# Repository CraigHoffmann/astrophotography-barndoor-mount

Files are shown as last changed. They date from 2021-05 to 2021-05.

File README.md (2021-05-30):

# Camera Barndoor Tracking Mount

Desktop barndoor mount for astrophotography with phd2/ascom autoguiding interface.

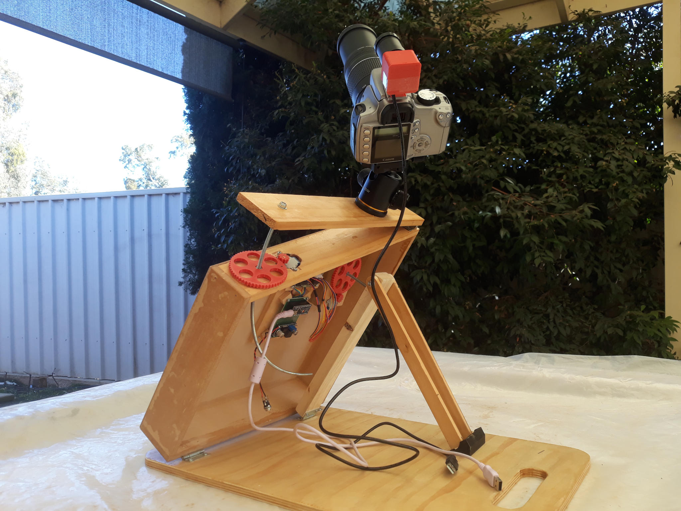
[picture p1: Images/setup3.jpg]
setup3


This started out as a basic barndoor mount with a hinge mounted on a tripod like many others.  However the cheap tripod I had wobbled too much and I decided to convert it into a tabletop mount.  I added an adjustable altitude axis for easy setup, then thought why not add an ascom interface so that it can be used with phd2 autoguiding for greater accuracy.  Now it a bit odd for a mount to be half alt/az and half equatorial axis (in this case Altitude and Right Ascention), but this seems to work fine for the phd2 guiding.  If polar aligned properly the altitude axis is almost redundant anyway.

The whole unit can be collapsed down for transport and storage.

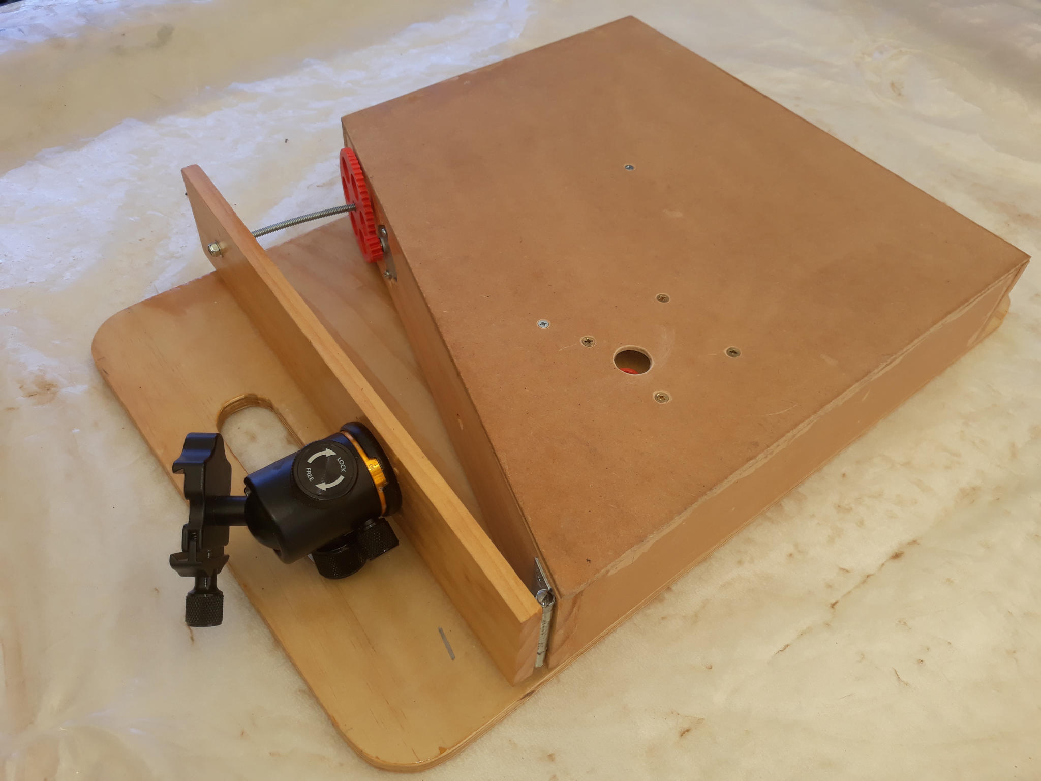
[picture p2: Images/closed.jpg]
closed


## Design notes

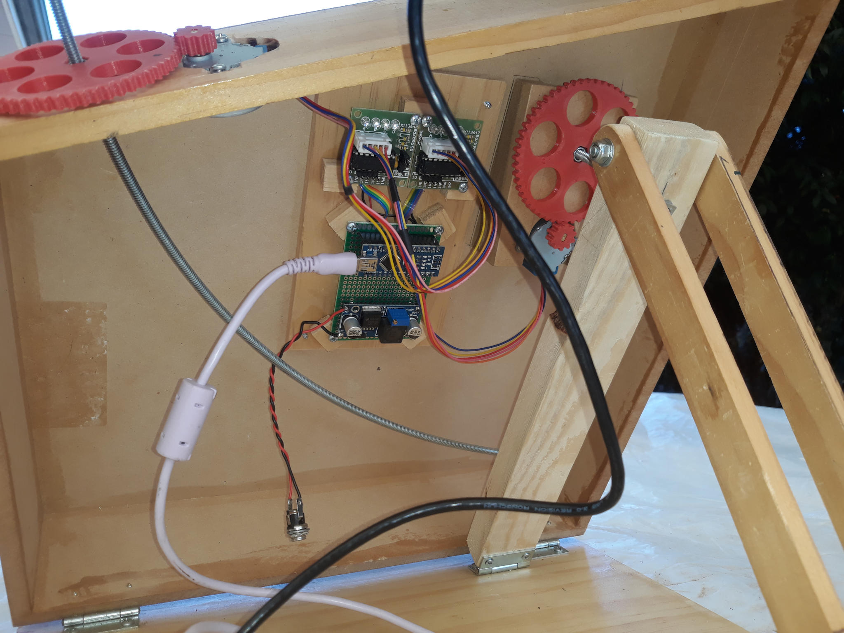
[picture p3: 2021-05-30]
Images/inside.jpg

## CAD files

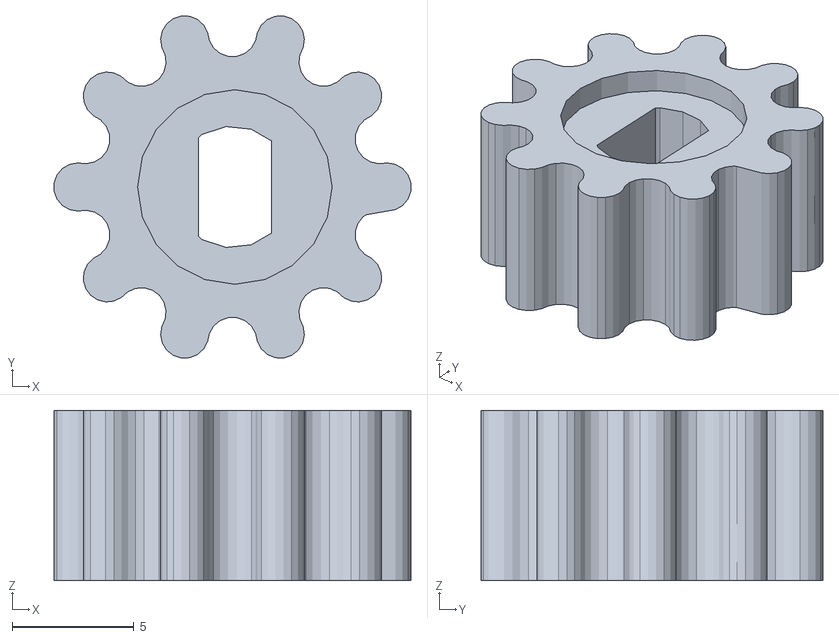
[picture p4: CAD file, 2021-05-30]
3Dprint/Barn Door Little gear.stl
14.7 x 14.1 x 7.00

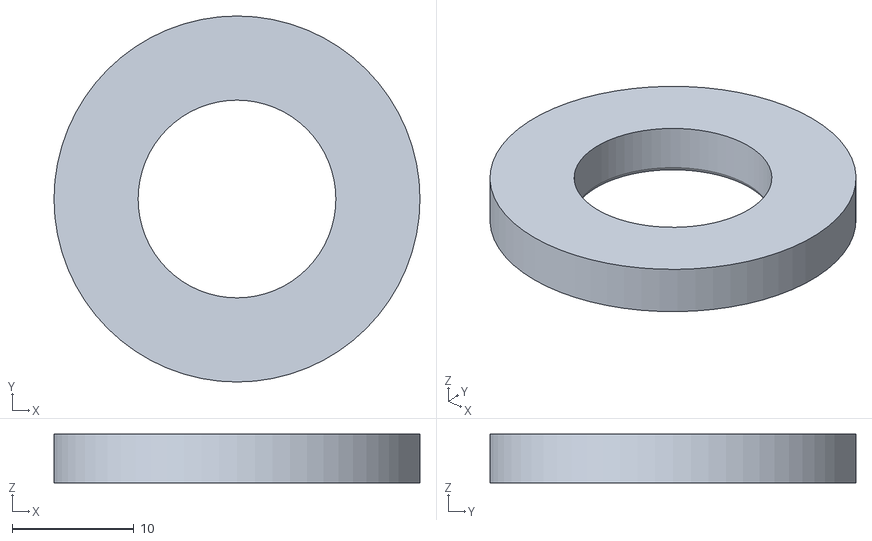
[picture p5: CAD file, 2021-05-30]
3Dprint/Barn Door ring.stl
30.0 x 30.0 x 4.00

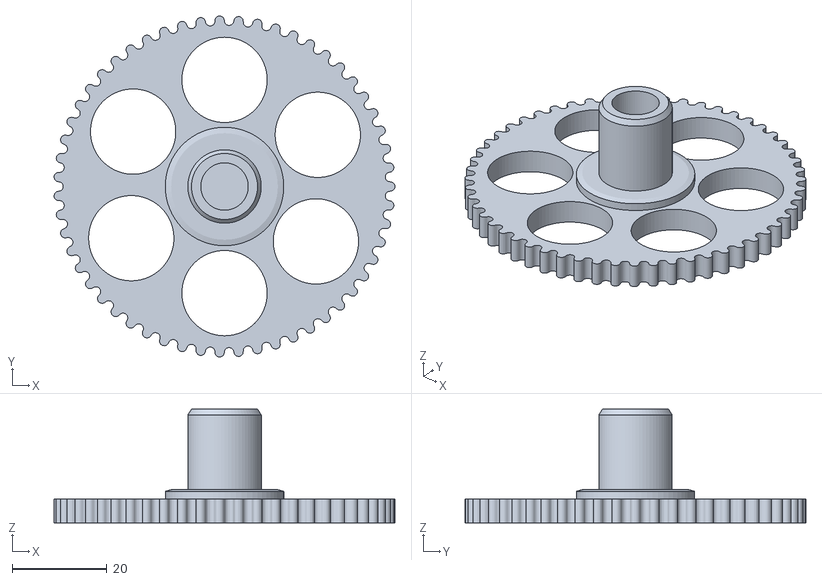
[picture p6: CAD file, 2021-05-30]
3Dprint/Barn Door Big gear.stl
71.9 x 72.0 x 24.0

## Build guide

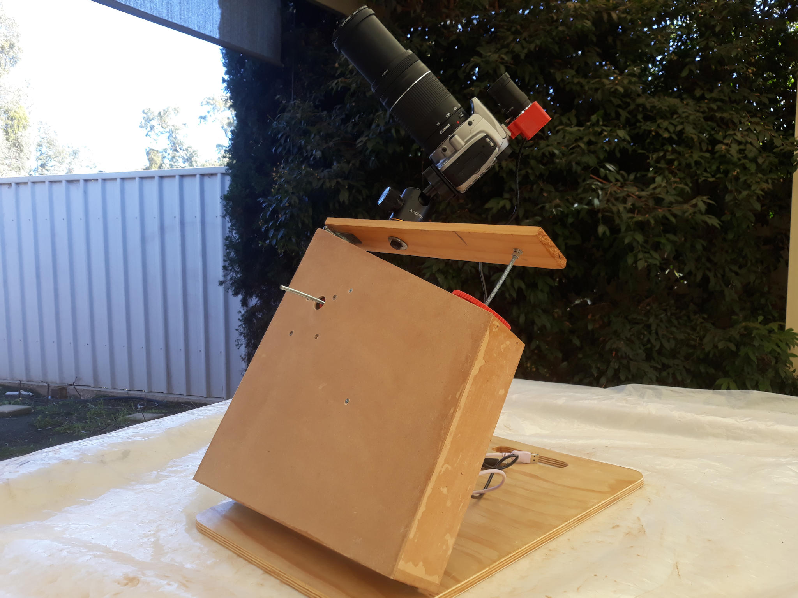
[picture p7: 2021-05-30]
Images/setup2.jpg

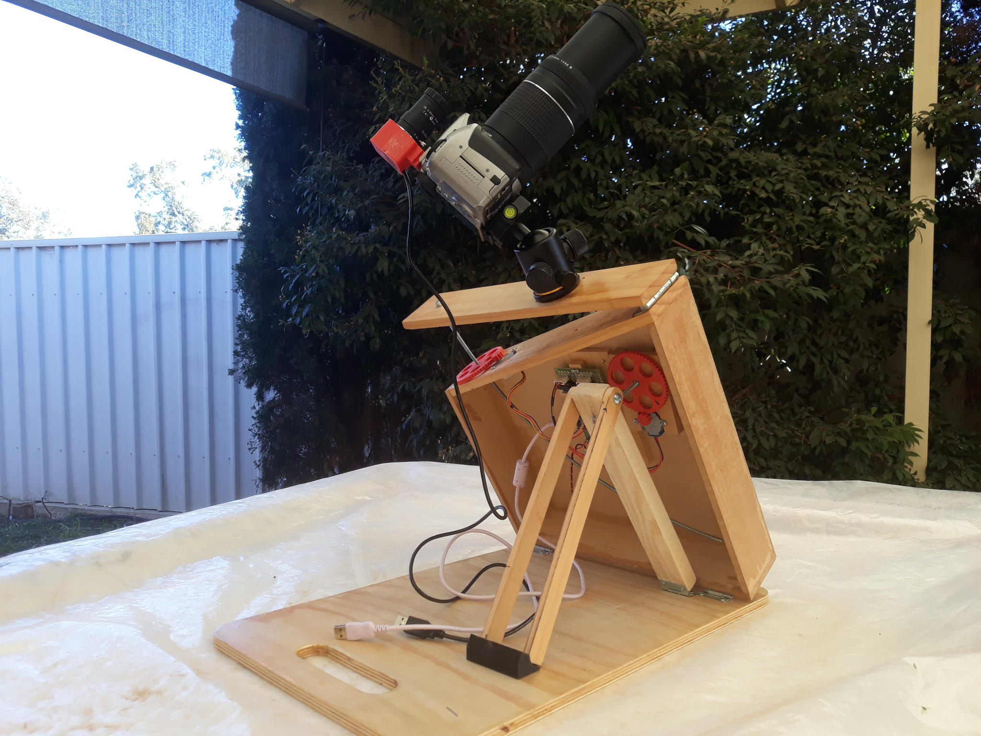
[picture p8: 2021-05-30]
Images/setup1.jpg

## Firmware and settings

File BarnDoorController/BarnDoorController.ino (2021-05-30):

// *********************************************************************************************************
// Astrophotography Barn Door (dual axis) and Camera controller with ASCOM autoguide interface
// Author: Craig Hoffmann  Jan 2021
//
// For more details refer to...   https://github.com/CraigHoffmann
//
// Driver Commands:
//  HI         Return OK to indicate controller is alive
//  G?         Return 0 if not currently pulse guiding or 1 if pulse guiding in progress
//  GN xxxxx   Guide North for xxxxx mS - Return OK immediately command received
//  GS, GE, GW As per GN above
//
// All commands sent by driver will be terminated by CR (should strip any LF sent from terminal interfaces)
// All command responses should be terminated by CR only
//
// *********************************************************************************************************

#include "src/myCmdArduino/myCmdArduino.h"    // Modified version of cmdArduino installed by library manager
#include <math.h>
#include <EEPROM.h>
#define EEPROM_HAS_DATA 888          // Used to flag s/w that EEPROM has been written data before


// *************************** USER CONFIGURATION FOR (MAIN) RA AXIS ***************************************
//                      Ensure all values to include decimal so calcs as double

#define RA_BARN_DOOR_RADIUS_mm         307.0        // distance from hinge point to thread (center of each)
#define RA_THREAD_PITCH_mm             1.05833      
#define RA_MOTOR_STEPS_PER_360deg      4076.0       // See note below - you may need to experiment
#define RA_SMALL_GEAR_TEETH            10.0
#define RA_BIG_GEAR_TEETH              55.0 
#define DEFAULT_GUIDE_RATE             0.5         // How much faster/slower than the sidereal rate (both axis)

// *************************** USER CONFIGURATION FOR DEC (ALT) AXIS ***************************************

#define ALT_AXIS_RADIUS_mm             260.0
#define ALT_THREAD_PITCH_mm            1.05833
#define ALT_MOTOR_STEPS_PER_360deg     4076.0       // See note below - you may need to experiment
#define ALT_SMALL_GEAR_TEETH           10.0
#define ALT_BIG_GEAR_TEETH             55.0 

// NOTE: In halfsetp mode one revolution of the output shaft of a 28BYJ-48 stepper takes 4096 steps, so 250 steps/sec
// results in roughly 3.5 rpm.  Important note: Manufacturers usually specify that the motors have a 64:1 gear reduction. 
// Some members of the Arduino Forums noticed that this wasn’t correct and so they took some motors apart to check 
// the actual gear ratio. They determined that the exact gear ratio is in fact 63.68395:1, which results in 
// approximately 4076 steps per full revolution of the output shaft (in half step mode).
//
// ********************************** END USER CONFIGURATION ************************************************



#define SHUTTER_OPEN 60              // Default Number Seconds Shutter is open
#define SHUTTER_DELAY 3              // Number Seconds before next Shutter trigger
#define PROCESS_PERIOD_mS 1000       // 1 second

#define TWOPI   6.28318530717959
#define SECONDS_IN_SIDEREAL_DAY   86164.0916
#define RA_TRACK_SPEED ((((TWOPI * RA_BARN_DOOR_RADIUS_mm) / RA_THREAD_PITCH_mm) * (RA_BIG_GEAR_TEETH / RA_SMALL_GEAR_TEETH)) / SECONDS_IN_SIDEREAL_DAY * RA_MOTOR_STEPS_PER_360deg)
#define RA_MAX_ADJUSTMENT_nS 10000
#define MAX_GUIDE_TIME_mS 60000

#define ALT_EQUIV_RA_SPEED ((((TWOPI * ALT_AXIS_RADIUS_mm) / ALT_THREAD_PITCH_mm) * (ALT_BIG_GEAR_TEETH / ALT_SMALL_GEAR_TEETH)) / SECONDS_IN_SIDEREAL_DAY * ALT_MOTOR_STEPS_PER_360deg)

#define RA_MOTOR 0
#define DEC_MOTOR 1

#define RA_GUIDE_BIT 0x01
#define DEC_GUIDE_BIT 0x02

#define RA_MotorPin1  6     // IN1 on the ULN2003 driver 1
#define RA_MotorPin2  5     // IN2 on the ULN2003 driver 1
#define RA_MotorPin3  4     // IN3 on the ULN2003 driver 1
#define RA_MotorPin4  3     // IN4 on the ULN2003 driver 1

#define DEC_MotorPin1  10    // IN1 on the ULN2003 driver 2
#define DEC_MotorPin2  9     // IN2 on the ULN2003 driver 2
#define DEC_MotorPin3  8     // IN3 on the ULN2003 driver 2
#define DEC_MotorPin4  7     // IN4 on the ULN2003 driver 2



// EEPROM stuff
struct EEPROM_Data_Object {
  unsigned long RA_StepAdjust_nS;
  unsigned int ShutterSpeed_S;
};

EEPROM_Data_Object MySaveData = {
  0,
  SHUTTER_OPEN
};


// Camera shutter timing variables
const int ShutterPin = A0;          // pin used for shutter control
int ShutterSeconds = 0;
unsigned int ShutterSpeed_S = SHUTTER_OPEN;
unsigned long PreviousMillis;

byte isGuiding = 0;

// RA Axis variables
unsigned long RA_PreviousStep_nS;
unsigned long RA_PreviousStep_uS;
unsigned long RA_CurrentStepPeriod_uS;
unsigned long RA_GuideTimeout_mS;
unsigned long RA_GuideStart_mS;
long RA_StepAdjust_nS = 0;  
byte RA_StepCount = 0;
float RA_guide = 0.0;


// DEC Axis variables
float DEC_Guide = 0;
unsigned long DEC_PreviousStep_uS;
unsigned long DEC_CurrentStepPeriod_uS;
unsigned long DEC_GuideTimeout_mS;
unsigned long DEC_GuideStart_mS;
byte DEC_StepCount = 0;



void setup() 
{
  // init the command line and set it for a speed of 57600
  cmd.begin(115200);

  // Add functions for dealing with command line input
  cmd.add("shutter", shutter);
  cmd.add("speed", shutter_speed);
  cmd.add("track", tracking);
  cmd.add("help", help);
  cmd.add("echo", echo);
  cmd.add("CONNECT", ascom_connect);
  cmd.add("DISCONNECT", ascom_disconnect);
  cmd.add("RA0", ascom_RA_reset);
  cmd.add("RA+", ascom_RA_inc);
  cmd.add("RA-", ascom_RA_dec);
  cmd.add("DEC0", ascom_DEC_reset);
  cmd.add("DEC+", ascom_DEC_inc);
  cmd.add("DEC-", ascom_DEC_dec);

  cmd.add("HI", ascom_HI);
  cmd.add("GQ", ascom_Guide_Query);
  cmd.add("GN", ascom_Guide_North);
  cmd.add("GS", ascom_Guide_South);
  cmd.add("GE", ascom_Guide_East);
  cmd.add("GW", ascom_Guide_West);
  cmd.add("GR", ascom_Guide_Rate_Query);

  ReadEEPROMData();
    
  pinMode(ShutterPin, OUTPUT);

  pinMode(RA_MotorPin1, OUTPUT);
  pinMode(RA_MotorPin2, OUTPUT);
  pinMode(RA_MotorPin3, OUTPUT);
  pinMode(RA_MotorPin4, OUTPUT);

  pinMode(DEC_MotorPin1, OUTPUT);
  pinMode(DEC_MotorPin2, OUTPUT);
  pinMode(DEC_MotorPin3, OUTPUT);
  pinMode(DEC_MotorPin4, OUTPUT);

  digitalWrite(ShutterPin, LOW);   // Shutter closed
  
  ShutterSeconds=-1;
  PreviousMillis = millis();
  RA_PreviousStep_uS = micros();
  RA_PreviousStep_nS = 0;

  RA_CurrentStepPeriod_uS = 1000000.0 / RA_TRACK_SPEED;        // Reset to default step period (in uS)
  RA_StepAdjust_nS = GetRemaining_nS(1000000.0 / RA_TRACK_SPEED);
  //Serial.println("calculations:");
  //Serial.println(RA_CurrentStepPeriod_uS);
  //Serial.println(RA_StepAdjust_nS);
  //Serial.println(RA_TRACK_SPEED);
  halfStep(RA_StepCount, RA_MOTOR);

  DEC_PreviousStep_uS = micros();
  DEC_CurrentStepPeriod_uS = (1000000.0 / ALT_EQUIV_RA_SPEED) / DEFAULT_GUIDE_RATE;       // Reset to default step period (in uS)
  halfStep(DEC_StepCount, DEC_MOTOR);

  RA_GuideTimeout_mS = MAX_GUIDE_TIME_mS;
  RA_GuideStart_mS = millis();
  DEC_GuideTimeout_mS = MAX_GUIDE_TIME_mS;
  DEC_GuideStart_mS = millis();

  while (!Serial);
  //Serial.println("\nINITIALIZED#");
}


void loop() 
{


  // Process every step period
  if ((micros() - RA_PreviousStep_uS) >= RA_CurrentStepPeriod_uS ) 
  {
    RA_PreviousStep_uS = RA_PreviousStep_uS + RA_CurrentStepPeriod_uS;                              // Update the last period
//    RA_CurrentStepPeriod_uS = (1000000.0 / (RA_TRACK_SPEED + (RA_TRACK_SPEED * RA_guide)));         // Update the tracking step period

    RA_CurrentStepPeriod_uS = (1000000.0 / RA_TRACK_SPEED) - ((1000000.0 / RA_TRACK_SPEED) * RA_guide);         // Update the tracking step period
    
//Serial.println(RA_CurrentStepPeriod_uS);
    // Fine tuning the step period (StepAdust_nS should always be positive)
    if (RA_guide == 0.0)
    {
      RA_PreviousStep_nS = RA_PreviousStep_nS + RA_StepAdjust_nS;       
      while (RA_PreviousStep_nS >= 1000)
      {
        RA_PreviousStep_nS = RA_PreviousStep_nS - 1000;
        RA_CurrentStepPeriod_uS = RA_CurrentStepPeriod_uS + 1;
      }
    }
    
    halfStep(RA_StepCount++, RA_MOTOR);
  }

  // Check if the current RA axis guide pulse has ended
  if ((millis() - RA_GuideStart_mS) >= RA_GuideTimeout_mS)
  {
    isGuiding = isGuiding & (!RA_GUIDE_BIT);
    RA_guide = 0.0;
    RA_GuideTimeout_mS = MAX_GUIDE_TIME_mS;   // Don't worry about checking again for a while
    RA_GuideStart_mS = millis();
  }


  // Process every DEC step period
  if ((micros() - DEC_PreviousStep_uS) >= DEC_CurrentStepPeriod_uS ) 
  {
    DEC_PreviousStep_uS = DEC_PreviousStep_uS + DEC_CurrentStepPeriod_uS;                // Update the last period
//    DEC_CurrentStepPeriod_uS = 1000000.0 / (ALT_EQUIV_RA_SPEED * DEFAULT_GUIDE_RATE);        // For simplicity just use the default RA guide - update this!!
//    DEC_CurrentStepPeriod_uS = (1000000.0 / ALT_EQUIV_RA_SPEED) - ((1000000.0 / ALT_EQUIV_RA_SPEED) * DEFAULT_GUIDE_RATE);        // For simplicity just use the default RA guide - update this!!

    if (DEC_Guide < 0.0)
    {
      DEC_CurrentStepPeriod_uS = ((1000000.0 / ALT_EQUIV_RA_SPEED) / abs(DEC_Guide));        // For simplicity just use the default RA guide - update this!!
      halfStep(DEC_StepCount--, DEC_MOTOR);
    }
    else if (DEC_Guide > 0.0)
    {
      DEC_CurrentStepPeriod_uS = ((1000000.0 / ALT_EQUIV_RA_SPEED) / abs(DEC_Guide));        // For simplicity just use the default RA guide - update this!!
      halfStep(DEC_StepCount++, DEC_MOTOR);
    }

  }

  // Check if the current DEC axis guide pulse has ended
  if ((millis() - DEC_GuideStart_mS) >= DEC_GuideTimeout_mS)
  {
    isGuiding = isGuiding & (!DEC_GUIDE_BIT);
    DEC_Guide = 0.0;
    DEC_GuideTimeout_mS = MAX_GUIDE_TIME_mS;   // Don't worry about checking again for a while
    DEC_GuideStart_mS = millis();
  }




  // Process every second
  if ((millis() - PreviousMillis) >= PROCESS_PERIOD_mS) 
  {
    PreviousMillis += PROCESS_PERIOD_mS;
    // Do stuff here - currently not required

    ShutterSeconds++;
    if (ShutterSeconds <= ShutterSpeed_S)
    {
      // Shutter Open
      digitalWrite(ShutterPin, HIGH);   // Shutter closed
    }
    else
    {
      // Shutter Closed
      digitalWrite(ShutterPin, LOW);   // Shutter closed
    }

    if (ShutterSeconds >= (ShutterSpeed_S + SHUTTER_DELAY))
    {
      ShutterSeconds = 0;
    }
  
  }

  // Check if there is any serial port activity and process
  cmd.poll();

}


void shutter(int argCnt, char **args)
{
  // Serial.println("rcvd cmd");

  if (argCnt>1)     // Must send "shutter close" or "shutter open"
  {
    //  Serial.println("have args");
    //  Serial.println(cmd.conv(args[1]));
    if (strcmp(args[1],"open")==0)   // if match then =0
    {
      Serial.println("**open shutter**");
    }
    else if (strcmp(args[1],"close")==0)     // if match then =0
    {
      Serial.println("**close shutter**");
    }
    
  }
}

void shutter_speed(int argCnt, char **args)
{
  unsigned int getSpeed = 0;
  getSpeed = ShutterSpeed_S;

  if (argCnt>1)     // Must send "track xxxxx" where xxxxx is a positive integer to increase step period or negative to decrease period (nano seconds per step)
  {
    getSpeed = cmd.conv(args[1]);
    if (getSpeed < 1)    // minimum 1 second
    {
      getSpeed = 1;
    }
    else if (getSpeed > 3600)    // maximum 1hr
    {
      getSpeed = 3600;
    }
    ShutterSpeed_S = getSpeed;
    WriteEEPROMData();
  }

  Serial.print("Shutter Speed set to ");    
  Serial.println(ShutterSpeed_S);    
}

void tracking(int argCnt, char **args)
{
  long adjustBy = 0;
  // Serial.println("rcvd cmd");
  adjustBy = RA_StepAdjust_nS;
  //Serial.println(adjustBy);
  
  if (argCnt>1)     // Must send "track xxxxx" where xxxxx is a positive integer to increase step period or negative to decrease period (nano seconds per step)
  {
    adjustBy = cmd.conv(args[1]);
    if (adjustBy > (RA_MAX_ADJUSTMENT_nS))
    {
      adjustBy = RA_MAX_ADJUSTMENT_nS;
    }
    else if (adjustBy < (-RA_MAX_ADJUSTMENT_nS))
    {
      adjustBy = (-RA_MAX_ADJUSTMENT_nS);
    }
    RA_StepAdjust_nS = adjustBy;
    WriteEEPROMData();
  }
  
  Serial.print("Tracking compensation set to ");    
  Serial.println(adjustBy);    
}

void help(int argCnt, char **args)
{
    Serial.println("------------------commands------------------");    
    Serial.println("track +/-xxxxxx to adjust tracking step period in nS");    
    Serial.println("shutter open|close|auto|single");    
    Serial.println("speed xxxx sets shutter speed in seconds (1 to 3600)");    
    Serial.println("echo on|off");    

}

// Turn command line echo on or off
void echo(int argCnt, char **args)
{
  if (argCnt>1)     
  {
    if (strcmp(args[1],"on")==0)   // if match then =0
    {
      cmd.echo(1);   
      Serial.println("echo turned on");    
    }
    else if (strcmp(args[1],"off")==0)   // if match then =0
    {
      cmd.echo(0);   
      Serial.println("echo turned off");    
    }
  }
}

// ********************************** NEW ASCOM INTERFACE ****************************

void ascom_HI(int argCnt, char **args)
{
  if (argCnt==1)       // The first arg is the command arg[0]     
  {
      cmd.echo(0);     // Ensure echo is off for direct ascom connection
      Serial.println("OK");    
  }
  else
  {
    Serial.println("ERR");
  }
}

void ascom_Guide_Rate_Query(int argCnt, char **args)
{
  if (argCnt>1)     
  {
    if (strcmp(args[1],"RA")==0)   // if match then =0
    {
      Serial.println(DEFAULT_GUIDE_RATE);    
    }
    else if (strcmp(args[1],"DEC")==0)   // if match then =0
    {
      Serial.println(DEFAULT_GUIDE_RATE);    
    }
  }
}


void ascom_Guide_Query(int argCnt, char **args)
{
  if (argCnt==1)       // The first arg is the command arg[0] so this checks there are no Args     
  {
    if (isGuiding != 0)
    {
      Serial.println("1");    // Guiding pulse in progress
    }
    else
    {
      Serial.println("0");    // Guiding pulse in progress
    }
  }
  else
  {
    Serial.println("ERR");
  }
}

void ascom_Guide_West(int argCnt, char **args)
{
  unsigned int Duration_mS = 0;
  
  if (argCnt>1)       // The first arg is the command arg[0] so this checks there is at least one parameter  
  {
    Duration_mS = cmd.conv(args[1]);
    if (Duration_mS < 0)
    {
      Duration_mS = 0;
    }
    else if (Duration_mS > MAX_GUIDE_TIME_mS)
    {
      Duration_mS = MAX_GUIDE_TIME_mS;
    }
    RA_guide = DEFAULT_GUIDE_RATE;
    RA_GuideTimeout_mS = Duration_mS;
    RA_GuideStart_mS = millis();
    isGuiding = isGuiding | RA_GUIDE_BIT;
  }
  else
  {
    RA_guide = 0.0;          // if no duration parameter default to 0 - stop N/S guiding 
    RA_GuideTimeout_mS = 0;
    isGuiding = isGuiding & (!RA_GUIDE_BIT);
  }
  Serial.println("OK");
}

void ascom_Guide_East(int argCnt, char **args)
{
  unsigned int Duration_mS = 0;
  
  if (argCnt>1)       // The first arg is the command arg[0] so this checks there is at least one parameter  
  {
    Duration_mS = cmd.conv(args[1]);
    if (Duration_mS < 0)
    {
      Duration_mS = 0;
    }
    else if (Duration_mS > MAX_GUIDE_TIME_mS)
    {
      Duration_mS = MAX_GUIDE_TIME_mS;
    }
    RA_guide = -DEFAULT_GUIDE_RATE;
    RA_GuideTimeout_mS = Duration_mS;
    RA_GuideStart_mS = millis();
    isGuiding = isGuiding | RA_GUIDE_BIT;
  }
  else
  {
    RA_guide = 0.0;          // if no duration parameter default to 0 - stop N/S guiding 
    RA_GuideTimeout_mS = 0;
    isGuiding = isGuiding & (!RA_GUIDE_BIT);
  }
  Serial.println("OK");
}


void ascom_Guide_North(int argCnt, char **args)
{
  unsigned int Duration_mS = 0;
  
  if (argCnt>1)       // The first arg is the command arg[0] so this checks there is at least one parameter  
  {
    Duration_mS = cmd.conv(args[1]);
    if (Duration_mS < 0)
    {
      Duration_mS = 0;
    }
    else if (Duration_mS > MAX_GUIDE_TIME_mS)
    {
      Duration_mS = MAX_GUIDE_TIME_mS;
    }
    DEC_Guide = -DEFAULT_GUIDE_RATE;
    DEC_GuideTimeout_mS = Duration_mS;
    DEC_GuideStart_mS = millis();
    isGuiding = isGuiding | DEC_GUIDE_BIT;
  }
  else
  {
    DEC_Guide = 0.0;          // if no duration parameter default to 0 - stop N/S guiding 
    DEC_GuideTimeout_mS = 0;
    isGuiding = isGuiding & (!DEC_GUIDE_BIT);
  }
  Serial.println("OK");
}


void ascom_Guide_South(int argCnt, char **args)
{
  unsigned int Duration_mS = 0;
  
  if (argCnt>1)       // The first arg is the command arg[0] so this checks there is at least one parameter  
  {
    Duration_mS = cmd.conv(args[1]);
    if (Duration_mS < 0)
    {
      Duration_mS = 0;
    }
    else if (Duration_mS > MAX_GUIDE_TIME_mS)
    {
      Duration_mS = MAX_GUIDE_TIME_mS;
    }
    DEC_Guide = DEFAULT_GUIDE_RATE;
    DEC_GuideTimeout_mS = Duration_mS;
    DEC_GuideStart_mS = millis();
    isGuiding = isGuiding | DEC_GUIDE_BIT;
  }
  else
  {
    DEC_Guide = 0.0;          // if no duration parameter default to 0 - stop N/S guiding 
    DEC_GuideTimeout_mS = 0;
    isGuiding = isGuiding & (!DEC_GUIDE_BIT);
  }
  Serial.println("OK");
}





// ******************************* OLD INTERFACE *******************************

void ascom_connect(int argCnt, char **args)
{
  if (argCnt==1)       // The first arg is the command arg[0]     
  {
      cmd.echo(0);
      Serial.println("OK#");    
  }
}

void ascom_disconnect(int argCnt, char **args)
{
  if (argCnt==1)       // The first arg is the command arg[0]     
  {
      Serial.println("OK#");    
  }
}

void ascom_RA_reset(int argCnt, char **args)
{
  if (argCnt==1)       // The first arg is the command arg[0]
  {
      RA_guide = 0.0;
      Serial.println("OK#");    
  }
}

void ascom_RA_inc(int argCnt, char **args)
{
  if (argCnt==1)       // The first arg is the command arg[0]    
  {
      RA_guide = DEFAULT_GUIDE_RATE;   // increase speed
      Serial.println("OK#");    
  }
}

void ascom_RA_dec(int argCnt, char **args)
{
  if (argCnt==1)       // The first arg is the command arg[0]  
  {
      RA_guide = -DEFAULT_GUIDE_RATE;    // decrease speed
      Serial.println("OK#");    
  }
}

void ascom_DEC_reset(int argCnt, char **args)
{
  if (argCnt==1)       // The first arg is the command arg[0]    
  {
      DEC_Guide = 0;
      Serial.println("OK#");    
  }
}

void ascom_DEC_inc(int argCnt, char **args)
{
  if (argCnt==1)       // The first arg is the command arg[0]   
  {
      DEC_Guide = 1;
      Serial.println("OK#");    
  }
}

void ascom_DEC_dec(int argCnt, char **args)
{
  if (argCnt==1)       // The first arg is the command arg[0]  
  {
      DEC_Guide = -1;
      Serial.println("OK#");    
  }
}

// *************************** END OLD INTERFACE *******************************

// 4 pin half step function
void halfStep(byte step, byte Motor)
{
  switch (step & 0x7)
  {
    case 0:    // 1000
      setOutputPins(0b1000,Motor);
      break;
      
    case 1:    // 1100
      setOutputPins(0b1100,Motor);
      break;
      
    case 2:    // 0100
      setOutputPins(0b0100,Motor);
      break;
      
    case 3:    // 0110
      setOutputPins(0b0110,Motor);
      break;
      
    case 4:    // 0010
      setOutputPins(0b0010,Motor);
      break;
      
    case 5:    // 0011
      setOutputPins(0b0011,Motor);
      break;
      
    case 6:    // 0001
      setOutputPins(0b0001,Motor);
      break;
      
    case 7:    //1001
      setOutputPins(0b1001,Motor);
      break;
  }
}


// Set the motor drive output pins
//
void setOutputPins(uint8_t mask, byte Motor)
{
  if (Motor == RA_MOTOR)
  {
    digitalWrite(RA_MotorPin1, (mask & 0x01) );        // Active High drive
    digitalWrite(RA_MotorPin2, ((mask>>1) & 0x01) );
    digitalWrite(RA_MotorPin3, ((mask>>2) & 0x01) );
    digitalWrite(RA_MotorPin4, ((mask>>3) & 0x01) );
  }
  else if (Motor == DEC_MOTOR)
  {
    digitalWrite(DEC_MotorPin1, (mask & 0x01) );        // Active High drive
    digitalWrite(DEC_MotorPin2, ((mask>>1) & 0x01) );
    digitalWrite(DEC_MotorPin3, ((mask>>2) & 0x01) );
    digitalWrite(DEC_MotorPin4, ((mask>>3) & 0x01) );
  }
}


void ReadEEPROMData(void)
{
  unsigned int CheckValue=0;
  EEPROM.get(0,CheckValue);
  if (CheckValue == EEPROM_HAS_DATA)
  {
    EEPROM.get(8 ,MySaveData);
    RA_StepAdjust_nS = MySaveData.RA_StepAdjust_nS;
    ShutterSpeed_S = MySaveData.ShutterSpeed_S;
  }
  else
  {
    WriteEEPROMData();
  }
  
}


void WriteEEPROMData(void)
{
  unsigned int CheckValue;
  CheckValue = EEPROM_HAS_DATA;
  MySaveData.RA_StepAdjust_nS = RA_StepAdjust_nS;
  MySaveData.ShutterSpeed_S = ShutterSpeed_S;
  EEPROM.put(0,CheckValue);
  EEPROM.put(8 ,MySaveData);
}



double GetRemaining_nS(double number)
{
    double fraction, integer;

    fraction = modf(number, &integer);
    // Serial.println("modf:");
    //Serial.println(number);
    //Serial.println(integer);
    //Serial.println(fraction);
    
    return (fraction * 1000.0);
}

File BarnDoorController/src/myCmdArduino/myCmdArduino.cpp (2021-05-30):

/*******************************************************************
    Modified version by Craig Hoffmann Jan 2021
    Original version from Arduino Library Manager (cmdArduino)
********************************************************************
*/	

/*******************************************************************
    Copyright (C) 2009 FreakLabs
    All rights reserved.

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
    1. Redistributions of source code must retain the above copyright
       notice, this list of conditions and the following disclaimer.
    2. Redistributions in binary form must reproduce the above copyright
       notice, this list of conditions and the following disclaimer in the
       documentation and/or other materials provided with the distribution.
    3. Neither the name of the the copyright holder nor the names of its contributors
       may be used to endorse or promote products derived from this software
       without specific prior written permission.

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
    Originally written by Christopher Wang aka Akiba.
    Please post support questions to the FreakLabs forum.

*******************************************************************/
/*!
    \file Cmd.c

    This implements a simple command line interface for the Arduino so that
    its possible to execute individual functions within the sketch. 
*/
/**************************************************************************/
#include <avr/pgmspace.h>
#if ARDUINO >= 100
#include <Arduino.h>
#else
#include <WProgram.h>
#endif
#include "HardwareSerial.h"
#include "myCmdArduino.h"

// command line message buffer and pointer
static uint8_t msg[MAX_MSG_SIZE];
static uint8_t *msg_ptr;

// linked list for command table
static cmd_t *cmd_tbl_list, *cmd_tbl;

// text strings for command prompt (stored in flash)
static uint8_t echo_enabled = 0;           // enable command input echo
const char cmd_banner[] PROGMEM = "";      // use \n for newline after banner
const char cmd_prompt[] PROGMEM = "";      // if want cmd prompt, use something like CMD: or >> 
const char cmd_unrecog[] PROGMEM = "ERR";  // Invalid command response

Cmd cmd;

/**************************************************************************/
/*!
    constructor
*/
/**************************************************************************/
Cmd::Cmd()
{

}

/**************************************************************************/
/*!
    Generate the main command prompt
*/
/**************************************************************************/
void Cmd::display()
{
    char buf[50];

    // Serial.println();            // *** craig removed
	strcpy_P(buf, cmd_banner);
    Serial.print(buf);              // *** craig changed println to print

    strcpy_P(buf, cmd_prompt);
    Serial.print(buf);
}

/**************************************************************************/
/*!
    Parse the command line. This function tokenizes the command input, then
    searches for the command table entry associated with the commmand. Once found,
    it will jump to the corresponding function.
*/
/**************************************************************************/
void Cmd::parse(char *cmd)
{
    uint8_t argc, i = 0;
    char *argv[30];
    char buf[50];
    cmd_t *cmd_entry;

    fflush(stdout);

    // parse the command line statement and break it up into space-delimited
    // strings. the array of strings will be saved in the argv array.
    argv[i] = strtok(cmd, " ");
    do
    {
        argv[++i] = strtok(NULL, " ");
    } while ((i < 30) && (argv[i] != NULL));
    
    // save off the number of arguments for the particular command.
    argc = i;

    // parse the command table for valid command. used argv[0] which is the
    // actual command name typed in at the prompt
    for (cmd_entry = cmd_tbl; cmd_entry != NULL; cmd_entry = cmd_entry->next)
    {
        if (!strcmp(argv[0], cmd_entry->cmd))
        {
            cmd_entry->func(argc, argv);
            display();
            return;
        }
    }

    // command not recognized. print message and re-generate prompt.
    strcpy_P(buf, cmd_unrecog);
    Serial.println(buf);

    display();
}

/**************************************************************************/
/*!
    This function processes the individual characters typed into the command
    prompt. It saves them off into the message buffer unless its a "backspace"
    or "enter" key. 
*/
/**************************************************************************/
void Cmd::handler()
{
    char c = Serial.read();

    switch (c)
    {
    case '\r':
        // terminate the msg and reset the msg ptr. then send
        // it to the handler for processing.
        *msg_ptr = '\0';
        //Serial.print("\r\n");
        parse((char *)msg);
        msg_ptr = msg;
        break;

    case '\n':
        // ignore newline characters. they usually come in pairs
        // with the \r characters we use for newline detection.
        break;
/*
    case '#':
        // # is used for the telescope command termination instead of \r\n
        // it to the handler for processing.
        *msg_ptr = '\0';
        parse((char *)msg);
        msg_ptr = msg;
        break;
*/    
    case '\b':
        // backspace 
        Serial.print(c);
        if (msg_ptr > msg)
        {
            msg_ptr--;
        }
        break;
    
    default:
        // normal character entered. add it to the buffer
        if (echo_enabled != 0)
		{
            Serial.print(c);
        }
        *msg_ptr++ = c;
        break;
    }
}

/**************************************************************************/
/*!
    This function should be set inside the main loop. It needs to be called
    constantly to check if there is any available input at the command prompt.
*/
/**************************************************************************/
void Cmd::poll()
{
    while (Serial.available())
    {
        handler();
    }
}

/**************************************************************************/
/*!
    Initialize the command line interface. This sets the terminal speed and
    and initializes things. 
*/
/**************************************************************************/
void Cmd::begin(uint32_t speed)
{
    // init the msg ptr
    msg_ptr = msg;

    // init the command table
    cmd_tbl_list = NULL;

    // default echo off
	echo_enabled = 0;

    // set the serial speed
    Serial.begin(speed);
}

void Cmd::echo(uint8_t enable)
{
    echo_enabled = enable;
}
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
